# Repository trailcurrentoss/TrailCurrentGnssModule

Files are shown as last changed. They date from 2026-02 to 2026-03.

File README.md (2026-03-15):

# TrailCurrent Bearing

GNSS (Global Navigation Satellite System) module for precise positioning, timing, and navigation. Part of the [TrailCurrent](https://trailcurrent.com) open-source vehicle platform.

## Project Overview

TrailCurrent Bearing is a standalone GNSS module that utilizes the DFRobot Gravity GNSS receiver. The data that comes in is formatted and sent over the CAN bus for other modules to use.

**Example Use Cases:**
- Digital clocks with precise time synchronization
- Navigation and geolocation devices
- Geospatial macros that control devices based on pinned locations
- Vehicle tracking and positioning systems

## Hardware Overview

- **Function:** Precision GNSS receiver with CAN bus interface
- **Key Features:**
  - DFRobot Gravity GNSS receiver supporting multiple satellite systems
  - CAN bus output for integration with TrailCurrent ecosystem
  - Flexible GNSS mode selection (GPS, BeiDou, GLONASS, combinations)
  - Hierarchical schematic design (5 sheets) for system modularity
  - Power management and signal conditioning

## Hardware Requirements

### Components

- **GNSS Receiver:**
  - DFRobot Gravity GNSS module with multi-constellation support

- **Microcontroller:**
  - ESP32 or equivalent for CAN interface and data processing

- **Power Management:**
  - Buck converter for regulated power supply

- **Interface:**
  - CAN transceiver for CAN bus communication
  - JST XH connectors for power and signal distribution

### KiCAD Library Dependencies

This project uses the consolidated [TrailCurrentKiCADLibraries](https://github.com/trailcurrentoss/TrailCurrentKiCADLibraries).

**Setup:**

```bash
# Clone the library
git clone git@github.com:trailcurrentoss/TrailCurrentKiCADLibraries.git

# Set environment variables (add to ~/.bashrc or ~/.zshrc)
export TRAILCURRENT_SYMBOL_DIR="/path/to/TrailCurrentKiCADLibraries/symbols"
export TRAILCURRENT_FOOTPRINT_DIR="/path/to/TrailCurrentKiCADLibraries/footprints"
export TRAILCURRENT_3DMODEL_DIR="/path/to/TrailCurrentKiCADLibraries/3d_models"
```

See [KICAD_ENVIRONMENT_SETUP.md](https://github.com/trailcurrentoss/TrailCurrentKiCADLibraries/blob/main/KICAD_ENVIRONMENT_SETUP.md) in the library repository for detailed setup instructions.

## Opening the Project

1. **Set up environment variables** (see Library Dependencies above)
2. **Open KiCAD:**
   ```bash
   kicad /path/to/EDA/trailcurrent-gps-module/trailcurrent-gps-module.kicad_pro
   ```
3. **Verify libraries load** - All symbol and footprint libraries should resolve without errors
4. **Navigate hierarchical sheets:**
   - Main sheet links to sub-modules for power management, GNSS interface, CAN interface, etc.
   - Each sheet is self-contained but references consolidated library components
5. **View 3D models** - Open PCB and press `Alt+3` to view the 3D visualization
   - All 3D models should load from the consolidated library path
   - Models use relative `${TRAILCURRENT_3DMODEL_DIR}` references

## Firmware

See `src/` directory for PlatformIO-based firmware implementing CAN bus communication and GNSS data processing.

**Setup:**
```bash
# Install PlatformIO (if not already installed)
pip install platformio

# Build firmware
pio run -d /path/to/project

# Upload to board
pio run -t upload -d /path/to/project
```

## GNSS Modes

The DFRobot Gravity receiver supports multiple satellite constellation configurations:

- **Mode 1:** GPS only
- **Mode 2:** BeiDou only
- **Mode 3:** GPS + BeiDou
- **Mode 4:** GLONASS only
- **Mode 5:** GPS + GLONASS
- **Mode 6:** BeiDou + GLONASS
- **Mode 7:** GPS + BeiDou + GLONASS (Maximum constellation)

Configure the desired mode in firmware initialization. Multi-constellation modes provide better coverage, especially in urban canyons and challenging environments.

## Manufacturing

- **PCB Files:** Ready for fabrication via standard PCB services (JLCPCB, OSH Park, etc.)
- **BOM Generation:** Export BOM from KiCAD schematic (Tools → Generate BOM)
- **JLCPCB Assembly:** This project supports automated assembly using JLCPCB
  - See [BOM_ASSEMBLY_WORKFLOW.md](https://github.com/trailcurrentoss/TrailCurrentKiCADLibraries/blob/main/BOM_ASSEMBLY_WORKFLOW.md) for detailed assembly workflow
  - Component library includes LCSC, Mouser, and DigiKey part numbers for flexible sourcing

## Project Structure

- **EDA/trailcurrent-gps-module/** - KiCAD schematic (5 sheets) and PCB design files
  - Main module sheet with sub-sheet references
  - Power management circuit
  - GNSS interface circuit
  - CAN interface circuit
  - Support circuits (regulators, filtering, etc.)
- **src/** - Firmware source code for GNSS data processing and CAN interface
- **lib/** - Custom libraries and dependencies
- **include/** - Header files

## Documentation

- **Main Schematic:** EDA/trailcurrent-gps-module/trailcurrent-gps-module.kicad_sch (with 5 sheet hierarchy)
- **PCB Layout:** EDA/trailcurrent-gps-module/trailcurrent-gps-module.kicad_pcb

## License

MIT License - See LICENSE file for details

This is open source hardware. You are free to use, modify, and distribute these designs for personal or commercial purposes.

## Contributing

Improvements and contributions are welcome! Please submit issues or pull requests to the main repository.

## Support

For questions about:
- **KiCAD setup:** See [KICAD_ENVIRONMENT_SETUP.md](https://github.com/trailcurrentoss/TrailCurrentKiCADLibraries/blob/main/KICAD_ENVIRONMENT_SETUP.md)
- **Library consolidation:** See [CONNECTOR_CONSOLIDATION_SUMMARY.md](https://github.com/trailcurrentoss/TrailCurrentKiCADLibraries/blob/main/CONNECTOR_CONSOLIDATION_SUMMARY.md)
- **Assembly workflow:** See [BOM_ASSEMBLY_WORKFLOW.md](https://github.com/trailcurrentoss/TrailCurrentKiCADLibraries/blob/main/BOM_ASSEMBLY_WORKFLOW.md)

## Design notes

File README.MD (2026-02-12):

# Project Overview
This project is a stand alone GNSS module that utlizes the DFRobot Gravity GNSS receiver. The data that comes in is then formatted and sent over the CAN bus for other modules to use.

Some example use cases are:
-  Digital Clocks
-  Navigation devices
-  Geospatial macros that control devices based on pinned locations

## Enums for GNSS Mode
 -- 1   eGPS              use gps
 -- 2   eBeiDou           use beidou
 -- 3   eGPS_BeiDou       use gps + beidou
 -- 4   eGLONASS          use glonass
 -- 5   eGPS_GLONASS      use gps + glonass
 -- 6   eBeiDou_GLONASS   use beidou +glonass
 -- 7   eGPS_BeiDou_GLONASS use gps + beidou + glonass

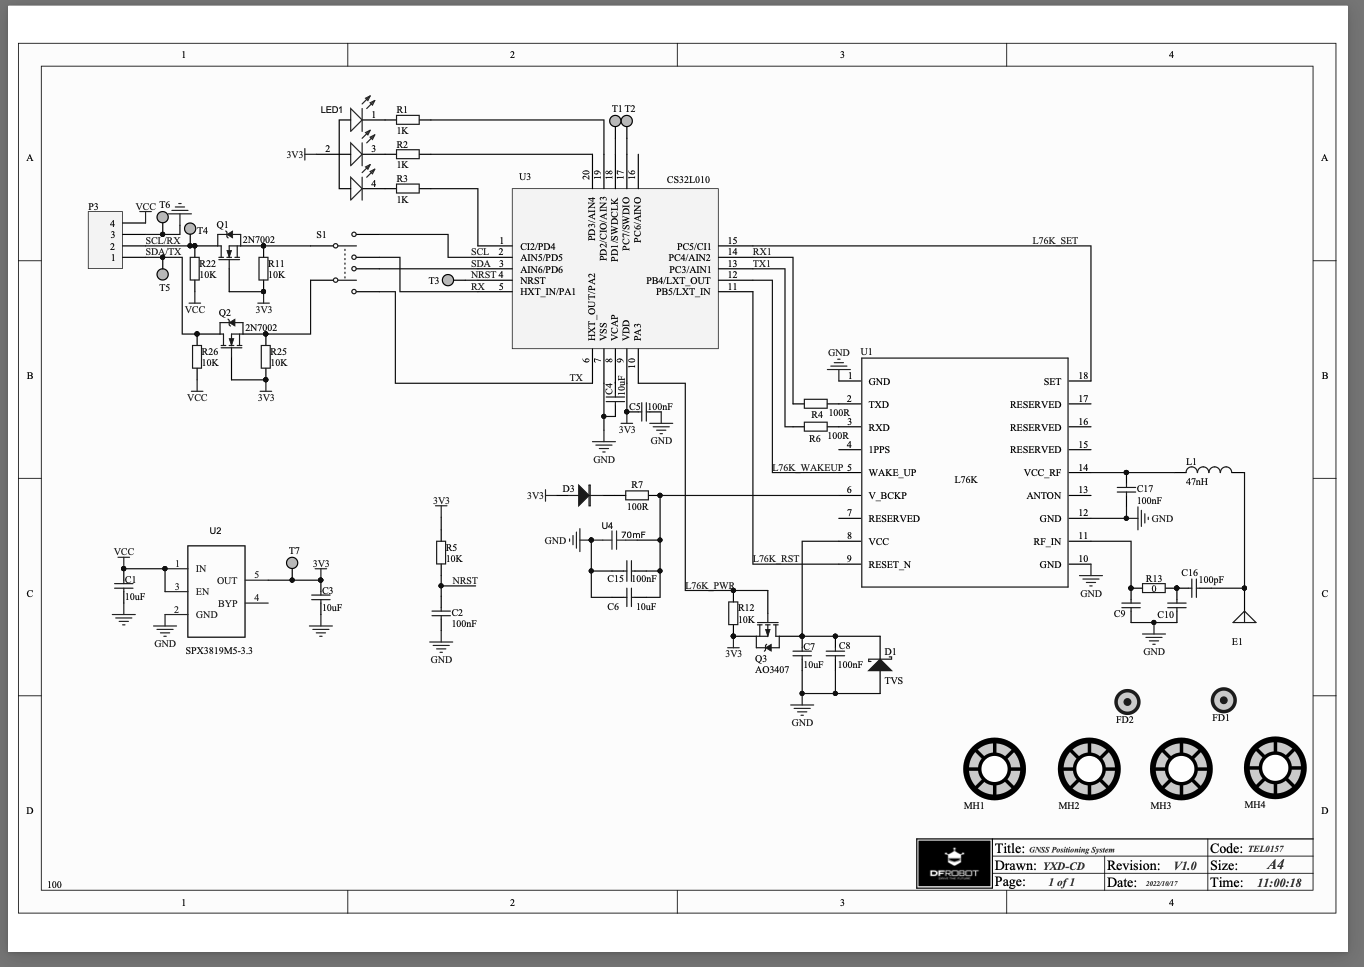
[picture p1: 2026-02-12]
EDA/DFRobot_Gnss_Schematic.png

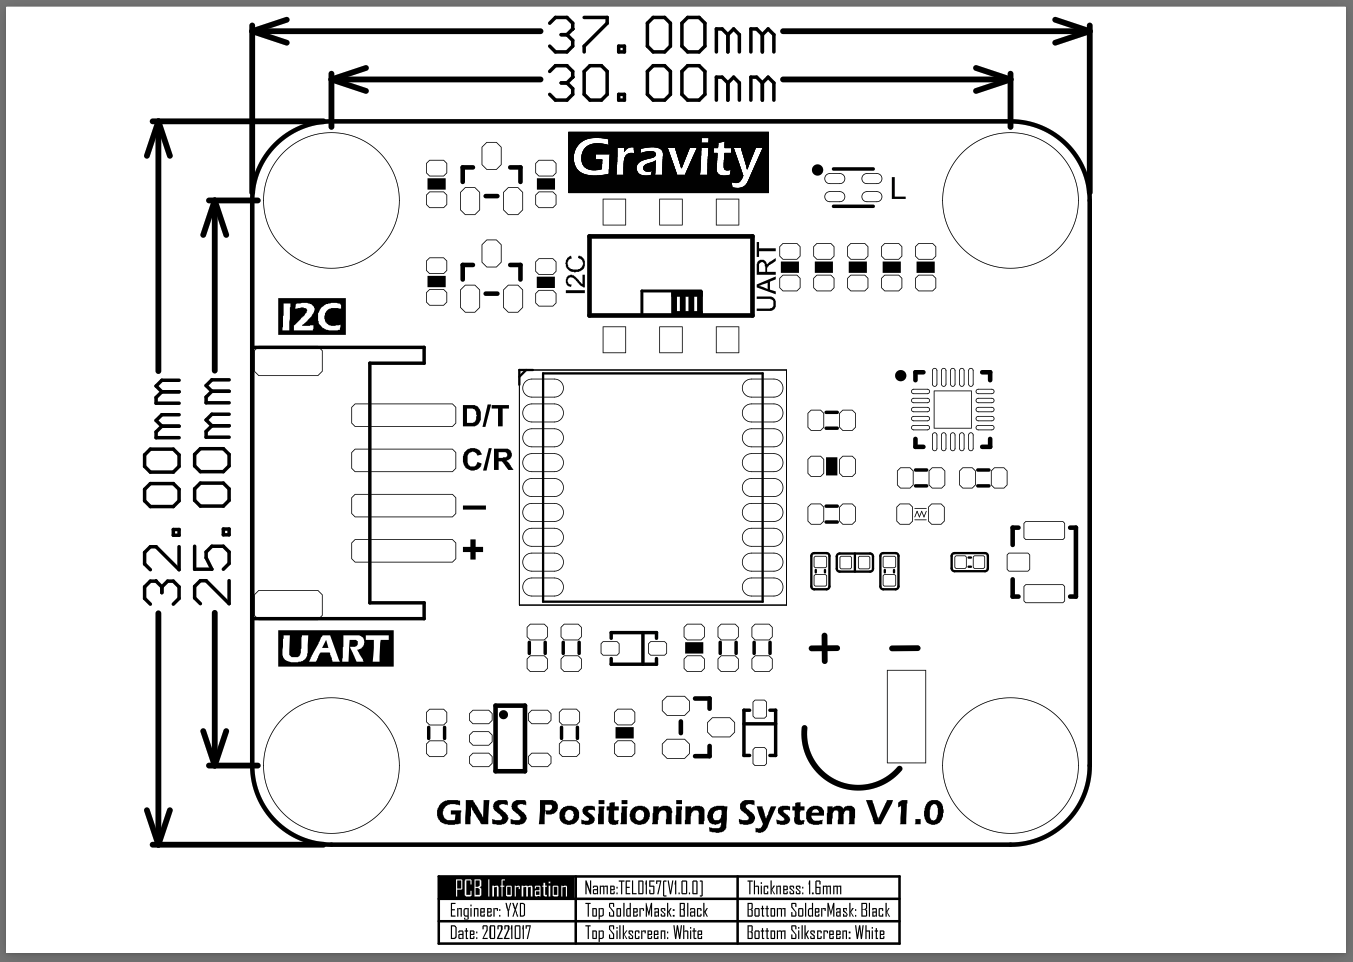
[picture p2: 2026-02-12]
CAD/DFRobotGnss.png

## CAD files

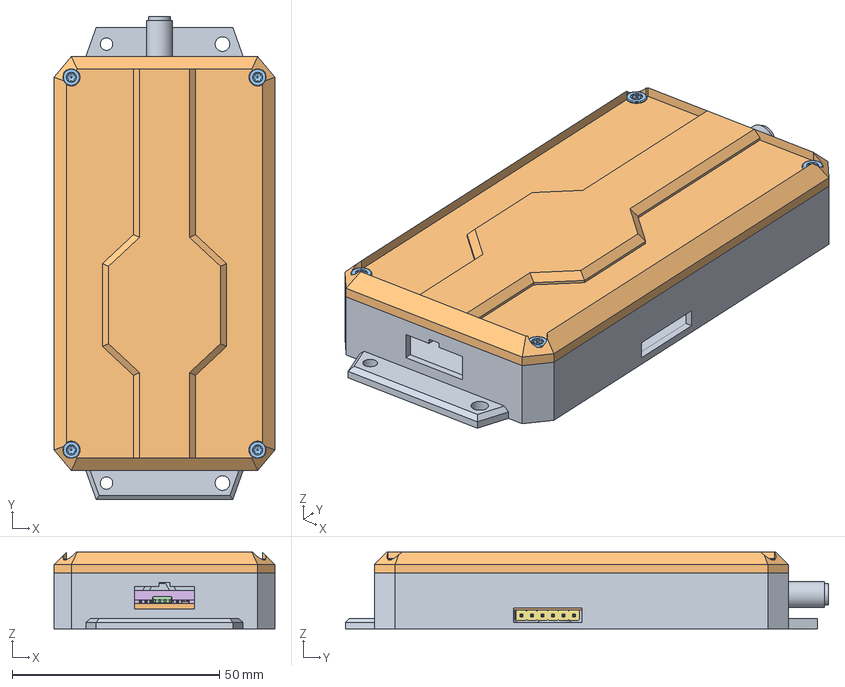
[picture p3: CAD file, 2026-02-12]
CAD/trailcurrent-gps-module-housing.FCStd
53.4 x 116.7 x 18.5 mm
BodyCaseBottom
Pcb_fbe4
C5_C_1206_3216Metric_9f1fbb0e91b7 x 6
U2_SOIC-8_3.9x4.9mm_P1.27mm_3940626bae83
R4_R_1206_3216Metric_6f3765b3a8a0 x 2
U3_ESP32-WROOM-32U_783dd3e30c39
J1_PinHeader_1x06_P254mm_Horizontal_b900b64528b3
BodyDFRobotGnss
BodySmaConnector
BodyCaseCover
M2.5x8-Screw x 4

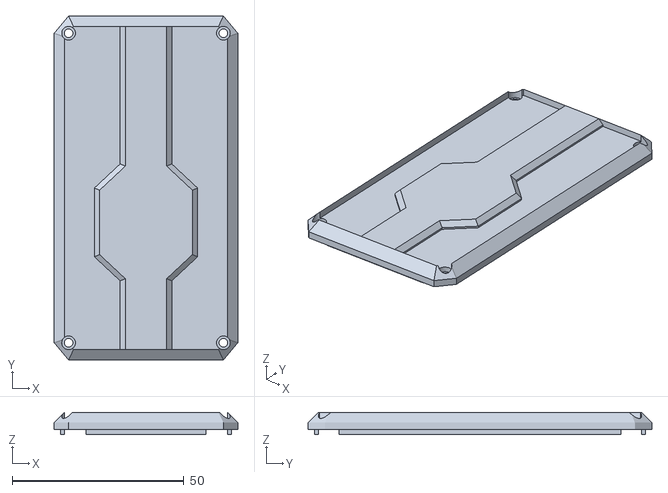
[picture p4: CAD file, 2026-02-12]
CAD/BodyCaseCover.stl
53.4 x 100.0 x 6.50

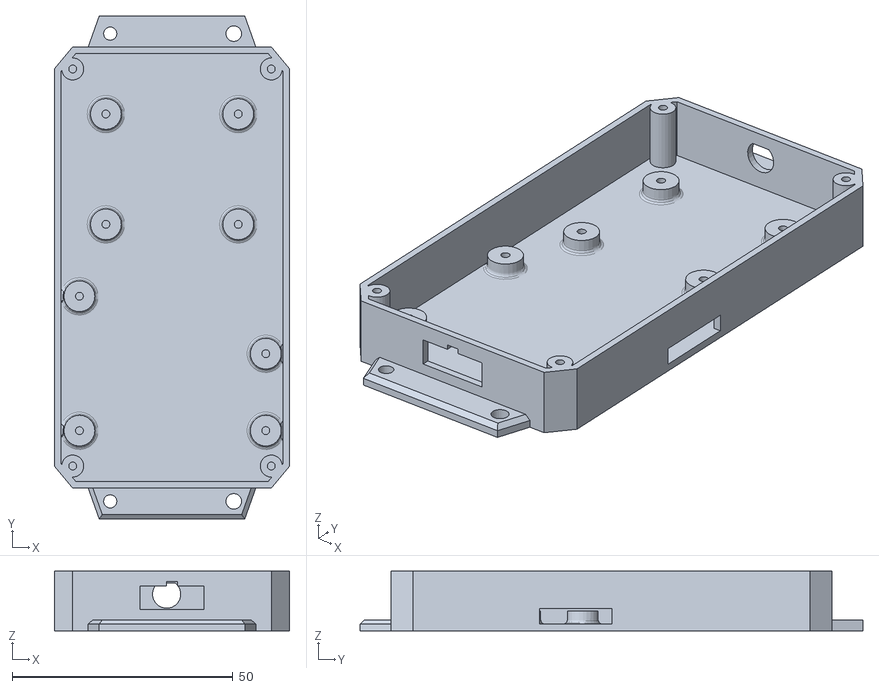
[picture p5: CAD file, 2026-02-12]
CAD/BodyCaseBottom.stl
53.4 x 114.0 x 13.5

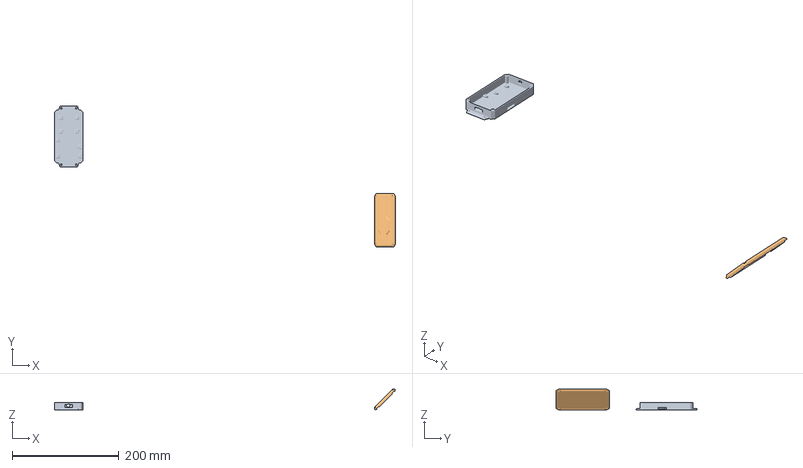
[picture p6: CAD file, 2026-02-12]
CAD/TrailCurrentGpsModuleCaseBottom.3mf
637.7 x 263.6 x 39.2 mm
BodyCaseBottomV4.stl
BodyCaseCover.stl

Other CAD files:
CAD/TrailCurrentGpsModuleCase.3mf

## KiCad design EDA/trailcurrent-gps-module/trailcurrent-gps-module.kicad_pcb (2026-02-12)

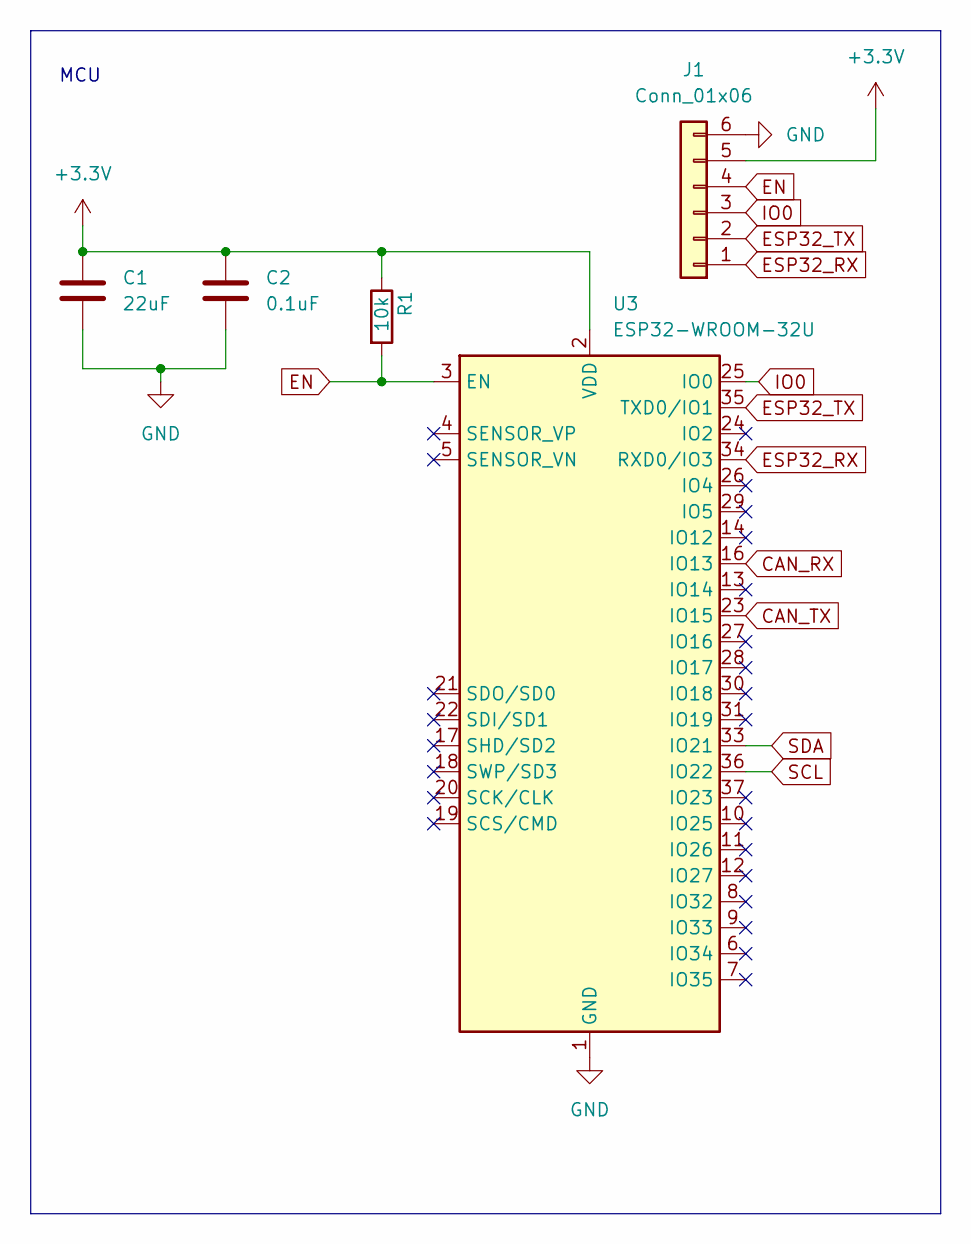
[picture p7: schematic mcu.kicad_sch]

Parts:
C1: 22uF; C_1206_3216Metric_Pad1.33x1.80mm_HandSolder
C2: 0.1uF; C_1206_3216Metric_Pad1.33x1.80mm_HandSolder
J1: Conn_01x06; PinHeader_1x06_P2.54mm_Horizontal
R1: 10k; R_1206_3216Metric_Pad1.30x1.75mm_HandSolder
U3: ESP32-WROOM-32U

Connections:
+3.3V: C1.1, C2.1, J1.5, R1.1, U3.2 (VDD); also elsewhere on the board
CAN_RX: U3.16 (IO13); also elsewhere on the board
CAN_TX: U3.23 (IO15); also elsewhere on the board
EN: J1.4, R1.2, U3.3 (EN)
ESP32_RX: J1.1, U3.34 (RXD0/IO3)
ESP32_TX: J1.2, U3.35 (TXD0/IO1)
GND: C1.2, C2.2, J1.6, U3.1 (GND), U3.15 (GND), U3.38 (GND), U3.39 (GND); also elsewhere on the board
IO0: J1.3, U3.25 (IO0)
SCL: U3.36 (IO22); also elsewhere on the board
SDA: U3.33 (IO21); also elsewhere on the board

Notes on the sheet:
MCU

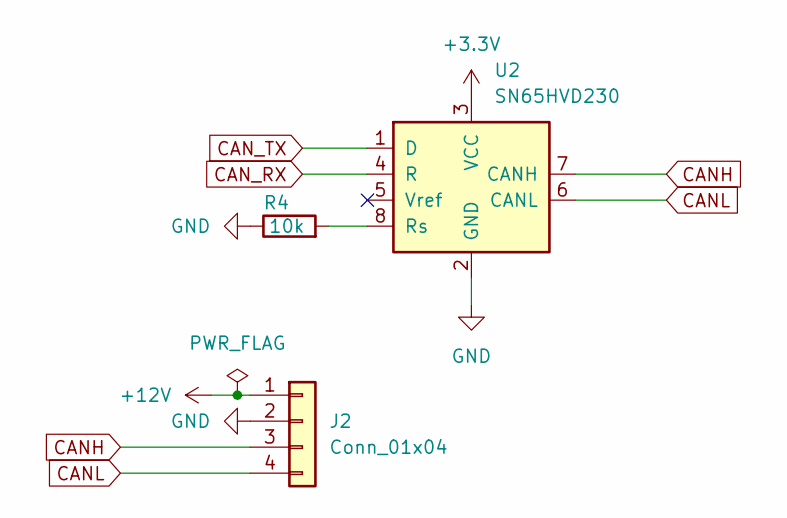
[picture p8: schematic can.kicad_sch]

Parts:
J2: Conn_01x04; CAN_PLUS_POWER
R4: 10k; R_1206_3216Metric_Pad1.30x1.75mm_HandSolder
U2: SN65HVD230; SOIC-8_3.9x4.9mm_P1.27mm

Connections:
+3.3V: U2.3 (VCC); also elsewhere on the board
+12V: J2.1; also elsewhere on the board
CANH: J2.3, U2.7 (CANH)
CANL: J2.4, U2.6 (CANL)
CAN_RX: U2.4 (R); also elsewhere on the board
CAN_TX: U2.1 (D); also elsewhere on the board
GND: J2.2, R4.1, U2.2 (GND); also elsewhere on the board
unnamed: R4.2, U2.8 (Rs)

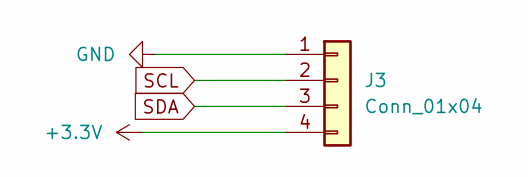
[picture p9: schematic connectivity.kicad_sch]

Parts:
J3: Conn_01x04; GenericPad_01x04

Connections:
+3.3V: J3.4; also elsewhere on the board
GND: J3.1; also elsewhere on the board
SCL: J3.2; also elsewhere on the board
SDA: J3.3; also elsewhere on the board

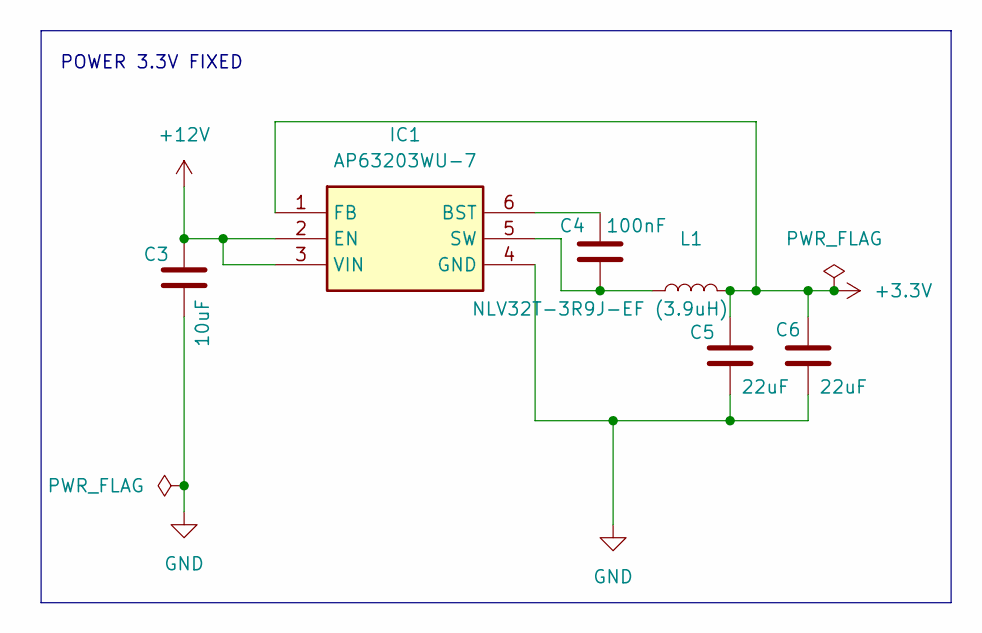
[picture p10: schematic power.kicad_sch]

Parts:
C3: 10uF; C_1206_3216Metric
C4: 100nF; C_1206_3216Metric
C5, C6: 22uF; C_1206_3216Metric_Pad1.33x1.80mm_HandSolder
IC1: AP63203WU-7; AP63203WU7; Mouser Part Number 621-AP63203WU-7
L1: NLV32T-3R9J-EF (3.9uH); NLV32T-3R9J-EF

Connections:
+3.3V: C5.1, C6.1, IC1.1 (FB), L1.2; also elsewhere on the board
+12V: C3.1, IC1.2 (EN), IC1.3 (VIN); also elsewhere on the board
GND: C3.2, C5.2, C6.2, IC1.4 (GND); also elsewhere on the board
unnamed: C4.1, IC1.6 (BST)
unnamed: C4.2, IC1.5 (SW), L1.1

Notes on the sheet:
POWER 3.3V FIXED

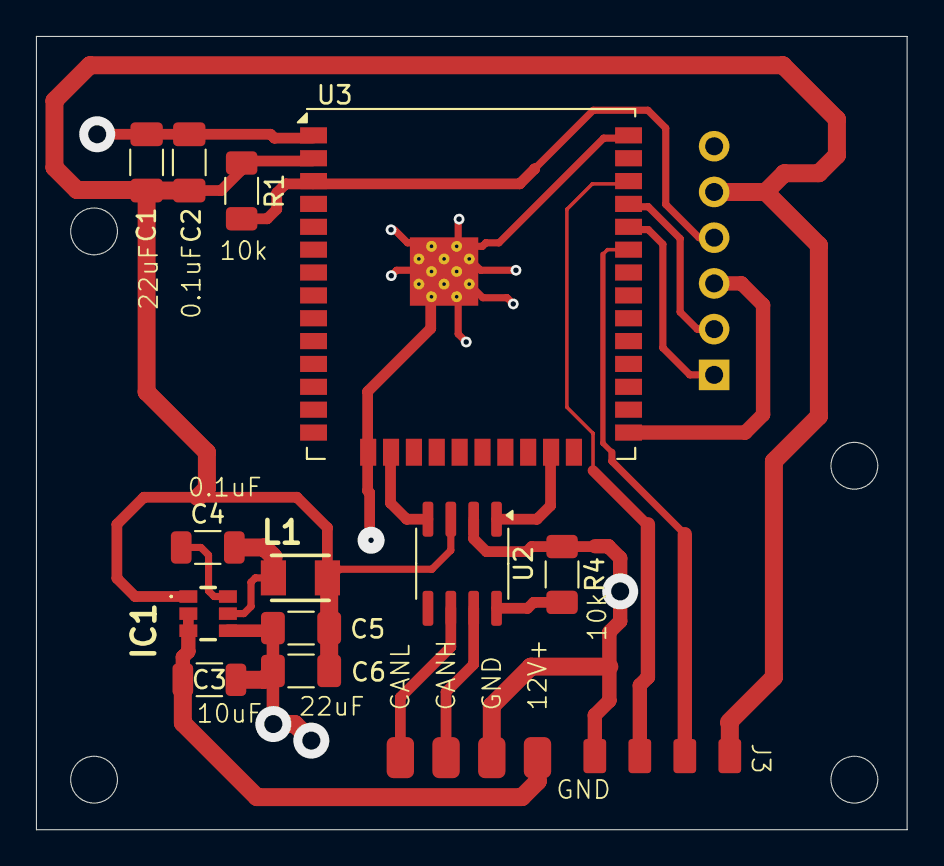
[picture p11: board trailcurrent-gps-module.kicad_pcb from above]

Board: 2 copper layers, 48.4 x 44.1 mm, 15 parts (1 on the bottom side), 16 nets.

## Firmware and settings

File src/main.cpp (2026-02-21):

#include "globals.h"
#include "i2cGps.h"
#include "canHelper.h"
#include <OtaUpdate.h>

// OTA update handler (3-minute timeout, credentials loaded from NVS at trigger time)
OtaUpdate otaUpdate(180000, "", "");

uint16_t currentYear = 0;
uint8_t currentMonth = 0;
uint8_t currentDay = 0;
uint8_t currentHour = 0;
uint8_t currentMinute = 0;
uint8_t currentSecond = 0;
float currentLatitude = 0.0;
float currentLongitude = 0.0;
double currentAltitude = 0.0;
uint8_t currentNumSatUsed = 0;
double currentSpeedOverGround = 0.0;
double currentCourseOverGround = 0.0;
uint8_t currentGnssMode = 0;

unsigned long updateStartMillis;
unsigned long currentUpdateMillis;
const unsigned long updateIntervalMillis = 100;

void setup()
{
  Serial.begin(115200);
  i2cGps::setup();
  canHelper::setupCan();
}

void loop()
{
  // RX is handled asynchronously by TwaiTaskBased FreeRTOS task

  currentUpdateMillis = millis();
  if (currentUpdateMillis - updateStartMillis >= updateIntervalMillis)
  {
    i2cGps::getGnssData(currentYear, currentMonth, currentDay, currentHour, currentMinute, currentSecond, currentLatitude, currentLongitude, currentAltitude, currentNumSatUsed, currentSpeedOverGround, currentCourseOverGround, currentGnssMode);
    canHelper::sendGnssData(currentYear, currentMonth, currentDay, currentHour, currentMinute, currentSecond, currentLatitude, currentLongitude, currentAltitude, currentNumSatUsed, currentSpeedOverGround, currentCourseOverGround, currentGnssMode);
    updateStartMillis = currentUpdateMillis;
  }
}

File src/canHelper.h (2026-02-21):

#pragma once
#include <Arduino.h>
#include <stdint.h>
#include "globals.h"
#include <TwaiTaskBased.h>
#include <OtaUpdate.h>
#include <Preferences.h>

#define CAN_RX 13
#define CAN_TX 15

// Forward declaration for OTA handler
extern OtaUpdate otaUpdate;

// WiFi credential reception state (CAN ID 0x01 protocol)
static bool wifiConfigInProgress = false;
static uint8_t wifiSsidBuffer[33];       // Max 32 chars + null
static uint8_t wifiPasswordBuffer[64];   // Max 63 chars + null
static uint8_t wifiSsidLen = 0;
static uint8_t wifiPasswordLen = 0;
static uint8_t wifiSsidReceived = 0;
static uint8_t wifiPasswordReceived = 0;

#define CAN_SEND_MESSAGE_LATLON_IDENTIFIER 0x009
#define CAN_SEND_MESSAGE_DATETIME_IDENTIFIER 0x006
#define CAN_SEND_MESSAGE_SATNUM_SPEED_COURSE_GNSSMODE_IDENTIFIER 0x007
#define CAN_SEND_MESSAGE_ALTITUDE_IDENTIFIER 0x008

namespace canHelper
{
    void saveWifiCredentials(const char* ssid, const char* password) {
        Preferences prefs;
        prefs.begin("wifi", false);  // read-write
        prefs.putString("ssid", ssid);
        prefs.putString("password", password);
        prefs.end();
        debugf("[WiFi] Credentials saved to NVS (SSID: %s)\n", ssid);
    }

    void handleWifiConfigMessage(const twai_message_t &message) {
        uint8_t msgType = message.data[0];

        switch (msgType) {
            case 0x01: {  // Start message
                wifiSsidLen = message.data[1];
                wifiPasswordLen = message.data[2];
                wifiSsidReceived = 0;
                wifiPasswordReceived = 0;
                memset(wifiSsidBuffer, 0, sizeof(wifiSsidBuffer));
                memset(wifiPasswordBuffer, 0, sizeof(wifiPasswordBuffer));
                wifiConfigInProgress = true;
                debugg("[WiFi] Config start: SSID len=%d, Password len=%d\n", wifiSsidLen, wifiPasswordLen);
                break;
            }

            case 0x02: {  // SSID chunk
                if (!wifiConfigInProgress) break;
                uint8_t dataBytes = message.data_length_code - 2;
                uint8_t remaining = wifiSsidLen - wifiSsidReceived;
                if (dataBytes > remaining) dataBytes = remaining;
                if (wifiSsidReceived + dataBytes <= 32) {
                    memcpy(wifiSsidBuffer + wifiSsidReceived, &message.data[2], dataBytes);
                    wifiSsidReceived += dataBytes;
                }
                break;
            }

            case 0x03: {  // Password chunk
                if (!wifiConfigInProgress) break;
                uint8_t dataBytes = message.data_length_code - 2;
                uint8_t remaining = wifiPasswordLen - wifiPasswordReceived;
                if (dataBytes > remaining) dataBytes = remaining;
                if (wifiPasswordReceived + dataBytes <= 63) {
                    memcpy(wifiPasswordBuffer + wifiPasswordReceived, &message.data[2], dataBytes);
                    wifiPasswordReceived += dataBytes;
                }
                break;
            }

            case 0x04: {  // End message with checksum
                if (!wifiConfigInProgress) break;
                wifiConfigInProgress = false;

                uint8_t checksum = 0;
                for (uint8_t i = 0; i < wifiSsidReceived; i++) checksum ^= wifiSsidBuffer[i];
                for (uint8_t i = 0; i < wifiPasswordReceived; i++) checksum ^= wifiPasswordBuffer[i];

                if (checksum == message.data[1] && wifiSsidReceived == wifiSsidLen && wifiPasswordReceived == wifiPasswordLen) {
                    wifiSsidBuffer[wifiSsidReceived] = '\0';
                    wifiPasswordBuffer[wifiPasswordReceived] = '\0';
                    saveWifiCredentials((const char*)wifiSsidBuffer, (const char*)wifiPasswordBuffer);
                } else {
                    debugf("[WiFi] Config failed: checksum %s\n",
                           (checksum == message.data[1]) ? "OK" : "MISMATCH");
                    debugg("[WiFi]   SSID %d/%d bytes\n", wifiSsidReceived, wifiSsidLen);
                    debugg("[WiFi]   Password %d/%d bytes\n", wifiPasswordReceived, wifiPasswordLen);
                }
                break;
            }
        }
    }

    static void handle_rx_message(const twai_message_t &message) {
        // OTA trigger message (ID 0x0)
        if (message.identifier == 0x0) {
            debugln("[OTA] CAN trigger received");

            String currentHostName = otaUpdate.getHostName();

            char targetHostName[14];
            sprintf(targetHostName, "esp32-%02X%02X%02X",
                    message.data[0], message.data[1], message.data[2]);

            debugf("[OTA] Target hostname:  '%s'\n", targetHostName);
            debugf("[OTA] Current hostname: '%s'\n", currentHostName.c_str());

            if (currentHostName.equals(targetHostName)) {
                debugln("[OTA] Hostname matched - reading WiFi credentials from NVS");
                Preferences prefs;
                prefs.begin("wifi", true);  // read-only
                String ssid = prefs.getString("ssid", "");
                String password = prefs.getString("password", "");
                prefs.end();

                if (ssid.length() > 0 && password.length() > 0) {
                    debugf("[OTA] Using stored WiFi credentials (SSID: %s)\n", ssid.c_str());
                    OtaUpdate ota(180000, ssid.c_str(), password.c_str());
                    ota.waitForOta();
                    debugln("[OTA] OTA mode exited - resuming normal operation");
                } else {
                    debugln("[OTA] ERROR: No WiFi credentials in NVS - cannot start OTA");
                }
            } else {
                debugln("[OTA] Hostname mismatch - ignoring OTA trigger");
            }
            return;
        }

        // WiFi credential configuration message (ID 0x01)
        if (message.identifier == 0x01) {
            handleWifiConfigMessage(message);
            return;
        }
    }

    static void handle_tx_result(bool success) {
        debugf("[CAN] TX %s\n", success ? "OK" : "FAILED");
    }

    void setupCan()
    {
        if (TwaiTaskBased::begin((gpio_num_t)CAN_TX, (gpio_num_t)CAN_RX, 500000, TWAI_MODE_NO_ACK)) {
            debugln("[CAN] Driver initialized");
        } else {
            debugln("[CAN] Failed to initialize driver");
            return;
        }

        TwaiTaskBased::onReceive(handle_rx_message);
        TwaiTaskBased::onTransmit(handle_tx_result);
        debugln("[CAN] RX/TX callbacks registered");
    }
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
